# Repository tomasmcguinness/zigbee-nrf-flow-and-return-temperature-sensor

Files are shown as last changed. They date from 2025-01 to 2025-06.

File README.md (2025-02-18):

# Zigbee Flow and Return Temperature Sensor on nRF52840

A Zigbee Sensor designed to monitor flow and return temperatures. The sensor provides two temperature sensor probes in a single unit. It can be used to monitor a boiler's flow and return temperatures or the difference between the tails of a radiator.

It uses two NTC Thermistors, which can be attached to the flow and return pipes on whatever you wish to measure; radiator tails, boiler flow and return, hot water cylinder. 

Battery powered, this sensor should run for over about a year and a half on a coin battery or around ten years on a 2000mAh battery.

> [!IMPORTANT] 
> This is still a work in progress. I have included a short list of items at the end of this README

## Parts

* 1 x Seeed XIAO nRF52840
* 2 x 10kΩ 0.1% resistors
* 2 x NTC Thermistors (I use these TT0P-10KC3-T105-1500)
* 1 x push button

## Wiring

In the diagram below, you would replace the two 10kΩ thermistor that are not on the breadboard with the actual probes



## Compiling 

This code has been developed using NCS (nRF Connect Software), with pin outs and battery reading chosen for the Seeed XIAO nrf52840. It should run on any nRF52840 with some tweaking. There is an overlay included for the nRF52840DK, which I use for development.

To compile, run the following command in an `nRF Connect` terminal. The pristine build (-p) flag isn't always necessary.

```
west build -b xiao_ble -p
```

## Flashing

The XIAO board can be flashed using two methods. The first is done using the factory installed bootloader. The second is done using a J-Link programmer. I have a J-Link programmer, so that's the method I've been using.

### UF2

> [!CAUTION] 
> Whilst this method *should* work, I haven't have any success! I want to make this project accessible to those without a J-Link, so I will dedicate time to it.

First, connect the board via USB to your computer. Next, double click the Reset button. A new USB drive should appear.

The compilation process will generate a UF2 firmware file and it will be be located here:

```
zigbee-nrf-flow-and-return-temperature-sensor\build\zigbee-nrf-flow-and-return-temperature-sensor\zephyr\zephyr.uf2
```

Just copy and paste this file onto the USB drive and the application *should* start. 

### J-Link

If you have a J-Link programmer, connect the board and run this command.

```
west flash
```

## Pairing

Once you have flashed the nRF52840 and powered it up, it will enter pairing mode. You can then add it to your Zigbee network using your usual method.

# NTC Thermistors

My Zigbee sensor was build with the TT0P-10KC3-T105-1500 probes, as I have already mentioned. These have a nominal resistance of 10kΩ @ 25°C and have a beta value of 3977. The relevant definitions in the code are here.

```
#define THERMISTORNOMINAL 10000
#define TEMPERATURENOMINAL 25
#define BCOEFFICIENT 3977
#define SERIESRESISTOR 10000
```

> [!NOTE] 
> If you want to use a different thermistor, you can change these values. I plan on making these configurable via the project, but for now you will need to change them directly in code.

# GPIOs

There several GPIOs configured by this project. These have been picked for the Seeed XIAO nRF52840 board.



| GPIO  | Usage |
| --- | --- |
| P0.03 | ADC (AIN1) pin for Probe 1  |
| P0.29 | ADC (AIN5) pin for Probe 2  |
| P0.28 | Power for the voltage dividers connected to the NTC temperature probes |
| P1.13 | Reset pin. Apply high for 10 seconds to reset the Zigbee configuration | 

# Zigbee ZCL

In order to maintain compatability, this sensor uses standard ZCL clusters rather.

There are three Endpoints 1, 5 & 7

Endpoint 1 contains the Basic cluster, the Identify Cluster and the Power Configuration Cluster.
Endpoint 5 contains a Temperature Measurement Cluster
Endpoint 7 contains a Temperature Measurement Cluster

# Home Assistant

I have tested my sensor on HomeAssistant using the ZHA integration and it displays pretty well. 



Unfortunately, the probe names are terrible.

```
sensor.coldbear_fart_sensor_temperature
sensor.coldbear_fart_sensor_temperature_2
```

I have tried to make a ZHA "Quirk" to display the probes like this:

```
sensor.coldbear_fart_sensor_flow_temperature
sensor.coldbear_fart_sensor_return_temperature
```

but I haven't had any success yet making it work how I want. I have included my work in progress in the project.

# Battery Life

I've invested a lot of time to try and ensure long battery life and I think I've gotten it to over a year on a coin battery! Average consumption is around 16µA



I've written quite a few blog posts detailing the journey, which are up on my blog. You can start here:

https://tomasmcguinness.com/2024/12/19/reducing-power-consumption-in-my-nrf52840-zigbee-sensor-with-the-help-of-a-nordic-semiconductors-power-profiler-ii-kit/

# Setup

Once powered up, you can add the device to your Zigbee network as you would any other Zigbee device.

# PCB

Using KiCAD, I have designed a PCB for this code. 

## V2
A mix of SMD and throughhole mountings, this revision fixes the traces for the reset button (issue in V1) and uses updated footprints for the JST connectors.



> [!CAUTION]
> The battery connections on this PCB are just very difficult to make. I've tried on three different boards, but I've not managed to power the XIAO using the battery terminal. If you had a finer soldering iron, you might have better luck.

## V3
To work around the battery terminal issue and make it easier to for amateurs like myself to solder, V3 has switched to a socket mount for the XIAO board. I also hope to use pogo pins to make the battery connections.



> [!NOTE]
> As of the 15th Feb 2025, I am waiting on the first fabricated versions of this board to verify the socket and pogo pin design will work. 

## V4
This is incomplete. The goal is to move to SMD mounting compleletely and introduce a CR2032 battery holder to make the unit complete. It's present in the PCB-V4 branch.

> [!CAUTION]
> V4 is a work in progress and not ready for use!

All the external connections for NTC probes and battery are via JST connectors.

If you are interested in buying a PCB, do let me know. If there is enough interest, I can place a bulk order.

# Support

If you want to support this project, please consider buying me a coffee!



# Next Steps

* [x] ~~Fix reset button PCB traces~~
* [x] ~~Use reset button to reverse probes i.e. swap readings~~
* [ ] Indicate when probes are swapped
* [ ] Confirm long-term reliability
* [ ] Ensure battery life

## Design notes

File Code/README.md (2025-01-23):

# Zigbee F.A.R.T. Sensor (Flow and Return Temperature)

A Zigbee Sensor designed to monitor flow and return temperatures. The sensor provides two temperature sensor probes in a single unit. It can be used to monitor a boiler's flow and return temperatures or the different between the tails of a radiator.

Battery powered, this sensor should run for over a year on a coin battery or 10 years on a 2000mAh battery.

## Compiling 

This code has been developed using NCS (nRF Connect Software), with pin outs and battery reading chosen for the Seeed XIAO nrf52840. It should run on any nRF52840 with some tweaking. 

To compile, run the following command in an `nRF Connect` terminal. The pristine build (-p) flag isn't always necessary.

```
west build -b xiao_ble -p
```

## Flashing

The XIAO board can be flashed using two methods. The first is done using the factory installed bootloader. The second is done using a J-Link programmer. I have a J-Link programmer, so that's the method I've been using.

### UF2

[!IMPORTANT]
Whilst this is supported, I have tried it without success! I want to make this project accessible to those without a J-Link, so I will dedicate time to it.

First, connect the board via USB to your computer. Next, double click the Reset button. A new USB drive should appear.

The compilation process will generate a UF2 firmware file and it will be be located here:

```
zigbee-nrf-flow-and-return-temperature-sensor\build\zigbee-nrf-flow-and-return-temperature-sensor\zephyr\zephyr.uf2
```

Just copy and paste this file onto the USB drive and the application *should* start. 

### J-Link

If you have a J-Link programmer, connect the board and run this command.

```
west flash
```

## GPIOs

There several GPIOs configured. These have been picked for the Seeed XIAO nRF52840 board.



P0.03 is the ADC (AIN1) pin for Probe 1
P0.28 is the ADC (AIN5) pin for Probe 2 
P0.28 providers power for the voltage dividers connected to the NTC temperature probes

P1.13 is the reset pin. Apply high for 10 seconds to reset the Zigbee configuration.

## Zigbee ZCL

In order to maintain compatability, this sensor uses standard ZCL clusters.

There are three Endpoints 1, 5 & 7

Endpoint 1 contains the Basic cluster, the Identify Cluster and the Power Configuration Cluster.
Endpoint 5 contains a Temperature Measurement Cluster
Endpoint 7 contains a Temperature Measurement Cluster

## Battery Life

I've invested a lot of time to try and ensure long battery life. I've written a few blog posts detailing the journey, which are up on my blog. You can start here:

https://tomasmcguinness.com/2024/12/19/reducing-power-consumption-in-my-nrf52840-zigbee-sensor-with-the-help-of-a-nordic-semiconductors-power-profiler-ii-kit/

# Setup

Once powered up, you can add the device to your Zigbee network as you would any other.

# PCB

I have designed a PCB for this code, but there are some flaws in it, so I'm not ready to make it public just yet! If you are interested in buying a PCB, let me know. If there are enough orders, the price per board can be quite low.

# Next Steps

* [ ] Use reset button to reverse probes i.e. swap readings
* [ ] Ensure reliability
* [ ] Ensure battery life

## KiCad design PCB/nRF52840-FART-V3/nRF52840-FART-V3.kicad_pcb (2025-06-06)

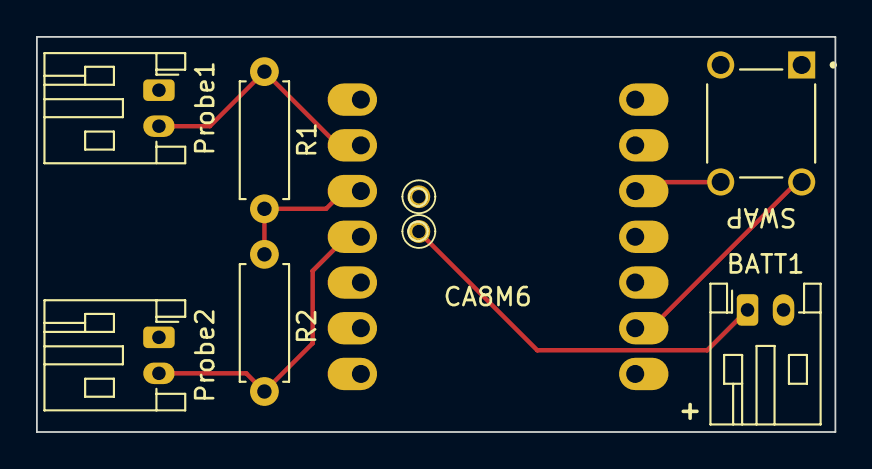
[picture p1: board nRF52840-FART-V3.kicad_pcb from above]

Board: 2 copper layers, 44.4 x 22.0 mm, 9 parts (0 on the bottom side), 7 nets.

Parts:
BATT1: Conn_01x02_Pin; JST_PH_S2B-PH-K_1x02_P2.00mm_Horizontal
J1, J2: 0914-3-15-20-77-14-11-0; 0914315207714110
Probe1, Probe2: Conn_01x02_Pin; JST_PH_S2B-PH-K_1x02_P2.00mm_Horizontal
R1, R2: 10K; R_Axial_DIN0207_L6.3mm_D2.5mm_P7.62mm_Horizontal
S1: TS02-66-55-BK-100-LCR-D; SW_TS02-66-55-BK-100-LCR-D
U1: xiao-ble; xiao-ble-tht

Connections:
+3.3V: S1.4, U1.12 (3V3)
+BATT: BATT1.1, J2.1
/dividerPower: R1.2, R2.2, U1.3 (A10/0.28)
/p1reading: Probe1.2, R1.1, U1.2 (A4/0.03_H)
/p2reading: Probe2.2, R2.1, U1.4 (A11/0.29)
/reset: S1.2, U1.9 (A7_SCK/1.13)
GND: BATT1.2, J1.1, Probe1.1, Probe2.1

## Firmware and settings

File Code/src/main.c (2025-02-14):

/*
 * Copyright (c) Cold Bear Ltd
 *
 * SPDX-License-Identifier: MIT
 */

#include <zephyr/kernel.h>
#include <zephyr/logging/log.h>
#include <zephyr/device.h>
#include <zephyr/devicetree.h>
#include <zephyr/drivers/adc.h>
#include <zephyr/drivers/gpio.h>
#include <zephyr/settings/settings.h>
#include <zephyr/pm/policy.h>
#include <zboss_api.h>
#include <zboss_api_addons.h>
#include <zigbee/zigbee_app_utils.h>
#include <zigbee/zigbee_error_handler.h>
#include <zb_nrf_platform.h>
#include <zb_zcl_reporting.h>
#include <zb_nrf_platform.h>
#include <zephyr/drivers/flash.h>
#include <zephyr/storage/flash_map.h>
#include <zephyr/fs/nvs.h>

#include "ha/zb_ha_temperature_sensor.h"

#include <math.h>

#include <dk_buttons_and_leds.h>
#include <ram_pwrdn.h>

#include "flash.h"

static struct nvs_fs fs;

/* This storage_partition is defined by the standard Zephyr Overlay */
#define NVS_PARTITION storage_partition
#define NVS_PARTITION_DEVICE FIXED_PARTITION_DEVICE(NVS_PARTITION)
#define NVS_PARTITION_OFFSET FIXED_PARTITION_OFFSET(NVS_PARTITION)

#define RED_LED_NODE DT_ALIAS(led0)
#define GREEN_LED_NODE DT_ALIAS(led1)
#define BLUE_LED_NODE DT_ALIAS(led2)

#define TEMPERATURE_DIVIDER_POWER_NODE DT_NODELABEL(temperature_divider_power)
#define ACTION_BUTTON_NODE DT_ALIAS(sw0)
#define BATTERY_DIVIDER_SINK_NODE DT_NODELABEL(battery_divider_sink)

#define APP_LOOP_INTERVAL_SEC 30
#define IDENTIFY_LED_BLINK_MSEC 100

#define SWAP_PROBES_PROBE_TIME K_SECONDS(1)

#define ZCL_TEMPERATURE_MEASUREMENT_MEASURED_VALUE_MULTIPLIER 100

#define INIT_BASIC_POWER_SOURCE ZB_ZCL_BASIC_POWER_SOURCE_BATTERY

#define INIT_BASIC_MANUF_NAME "coldbear"
#define INIT_BASIC_MODEL_ID "FART Sensor"
#define INIT_BASIC_HW_VERSION 11
#define INIT_BASIC_SW_VERSION "v0.1"
#define INIT_BASIC_APP_VERSION 01
#define INIT_BASIC_STACK_VERSION 10

#define FART_ENDPOINT 1
#define PROBE_1_ENDPOINT 5
#define PROBE_2_ENDPOINT 7

#define BATTERY_ADC_CHANNEL 2

#define DT_SPEC_AND_COMMA(node_id, prop, idx) ADC_DT_SPEC_GET_BY_IDX(node_id, idx),

static const struct adc_dt_spec adc_channels[] = {DT_FOREACH_PROP_ELEM(DT_PATH(zephyr_user), io_channels, DT_SPEC_AND_COMMA)};

static const struct adc_dt_spec adc_channels[];

struct swap_probes_context_t
{
	uint32_t button;
	bool swap_done;
	struct k_timer timer;
};
static struct swap_probes_context_t swap_probes_context;

static bool probes_swapped = false;

// TODO Move this to configuration, so they can be easily changed.
//
#define THERMISTORNOMINAL 10000
#define TEMPERATURENOMINAL 25
#define BCOEFFICIENT 3977
#define SERIESRESISTOR 10000

static const struct gpio_dt_spec red_led = GPIO_DT_SPEC_GET(RED_LED_NODE, gpios);
static const struct gpio_dt_spec green_led = GPIO_DT_SPEC_GET(GREEN_LED_NODE, gpios);
static const struct gpio_dt_spec blue_led = GPIO_DT_SPEC_GET(BLUE_LED_NODE, gpios);
static const struct gpio_dt_spec temperatures_divider_power = GPIO_DT_SPEC_GET(TEMPERATURE_DIVIDER_POWER_NODE, gpios);
static const struct gpio_dt_spec battery_divider_sink = GPIO_DT_SPEC_GET(BATTERY_DIVIDER_SINK_NODE, gpios);

LOG_MODULE_REGISTER(app, LOG_LEVEL_DBG);

typedef struct
{
	zb_uint8_t battery_voltage;
	zb_uint8_t battery_size;
	zb_uint8_t battery_quantity;
	zb_uint8_t battery_rated_voltage;
	zb_uint8_t battery_alarm_mask;
	zb_uint8_t battery_voltage_min_threshold;
	zb_uint8_t battery_percentage_remaining;
	zb_uint8_t battery_voltage_threshold1;
	zb_uint8_t battery_voltage_threshold2;
	zb_uint8_t battery_voltage_threshold3;
	zb_uint8_t battery_percentage_min_threshold;
	zb_uint8_t battery_percentage_threshold1;
	zb_uint8_t battery_percentage_threshold2;
	zb_uint8_t battery_percentage_threshold3;
	zb_uint32_t battery_alarm_state;

} zb_zcl_power_config_battery_attrs_t;

struct zb_device_ctx
{
	zb_zcl_basic_attrs_ext_t basic_attr;
	zb_zcl_identify_attrs_t identify_attr;
	zb_zcl_temp_measurement_attrs_t probe_1_measure_attrs;
	zb_zcl_temp_measurement_attrs_t probe_2_measure_attrs;
	zb_zcl_power_config_battery_attrs_t power_config_attrs;
};

static struct zb_device_ctx dev_ctx;

struct battery_level_point
{
	// Percentage at #lvl_mV.
	uint8_t lvl_percentage;

	// Voltage at #lvl_percentage remaining life. */
	uint16_t lvl_mV;
};

/** A discharge curve specific to the power source. */
static const struct battery_level_point levels[] = {
	/* "Curve" here eyeballed from captured data for the [Adafruit
	 * 3.7v 2000 mAh](https://www.adafruit.com/product/2011) LIPO
	 * under full load that started with a charge of 3.96 V and
	 * dropped about linearly to 3.58 V over 15 hours.  It then
	 * dropped rapidly to 3.10 V over one hour, at which point it
	 * stopped transmitting.
	 *
	 * Based on eyeball comparisons we'll say that 15/16 of life
	 * goes between 3.95 and 3.55 V, and 1/16 goes between 3.55 V
	 * and 3.1 V.
	 */

	{100, 3700},
	{6, 3550},
	{0, 3100},
};

//------------
// Prototypes
//

void zboss_signal_handler(zb_bufid_t bufid);
static void zcl_device_cb(zb_bufid_t bufid);
static void configure_gpio(void);
static void app_clusters_attr_init(void);
static void identify_cb(zb_bufid_t bufid);
static void button_handler(uint32_t button_state, uint32_t has_changed);
static void toggle_identify_led(zb_bufid_t bufid);
static int read_battery();
static int read_temperatures();
void check_swap_probes_button(uint32_t button_state, uint32_t has_changed);
static void swap_probes_timer_expired(struct k_timer *timer_id);
static void register_swap_probes_button(uint8_t button);

ZB_ZCL_DECLARE_IDENTIFY_ATTRIB_LIST(
	identify_attr_list,
	&dev_ctx.identify_attr.identify_time);

ZB_ZCL_DECLARE_BASIC_ATTRIB_LIST_EXT(
	ext_attr_list,
	&dev_ctx.basic_attr.zcl_version,
	&dev_ctx.basic_attr.app_version,
	&dev_ctx.basic_attr.stack_version,
	&dev_ctx.basic_attr.hw_version,
	&dev_ctx.basic_attr.mf_name,
	&dev_ctx.basic_attr.model_id,
	&dev_ctx.basic_attr.zcl_version,
	&dev_ctx.basic_attr.power_source,
	&dev_ctx.basic_attr.location_id,
	&dev_ctx.basic_attr.ph_env,
	&dev_ctx.basic_attr.sw_ver);

// This must be declared for compilate to succeed.
// https://devzone.nordicsemi.com/f/nordic-q-a/85315/zboss-declare-power-config-attribute-list-for-battery-bat_num
#define bat_num

ZB_ZCL_DECLARE_POWER_CONFIG_BATTERY_ATTRIB_LIST_EXT(power_config_attr_list,
													&dev_ctx.power_config_attrs.battery_voltage,
													&dev_ctx.power_config_attrs.battery_size,
													&dev_ctx.power_config_attrs.battery_quantity,
													&dev_ctx.power_config_attrs.battery_rated_voltage,
													&dev_ctx.power_config_attrs.battery_alarm_mask,
													&dev_ctx.power_config_attrs.battery_voltage_min_threshold,
													&dev_ctx.power_config_attrs.battery_percentage_remaining,
													&dev_ctx.power_config_attrs.battery_voltage_threshold1,
													&dev_ctx.power_config_attrs.battery_voltage_threshold2,
													&dev_ctx.power_config_attrs.battery_voltage_threshold3,
													&dev_ctx.power_config_attrs.battery_percentage_min_threshold,
													&dev_ctx.power_config_attrs.battery_percentage_threshold1,
													&dev_ctx.power_config_attrs.battery_percentage_threshold2,
													&dev_ctx.power_config_attrs.battery_percentage_threshold3,
													&dev_ctx.power_config_attrs.battery_alarm_state);

ZB_ZCL_DECLARE_FART_SENSOR_CLUSTER_LIST(fart_sensor_clusters, ext_attr_list, identify_attr_list, power_config_attr_list);
ZB_HA_DECLARE_FART_SENSOR_EP(fart_sensor_ep, FART_ENDPOINT, fart_sensor_clusters);

ZB_ZCL_DECLARE_TEMP_MEASUREMENT_ATTRIB_LIST(temp_measurement_attr_list_1,
											&dev_ctx.probe_1_measure_attrs.measure_value,
											&dev_ctx.probe_1_measure_attrs.min_measure_value,
											&dev_ctx.probe_1_measure_attrs.max_measure_value,
											&dev_ctx.probe_1_measure_attrs.tolerance);

ZB_HA_DECLARE_TEMPERATURE_SENSOR_CLUSTER_LIST(temperature_sensor_clusters_1, temp_measurement_attr_list_1);
ZB_HA_DECLARE_TEMPERATURE_SENSOR_EP_1(temperature_sensor_ep_one, PROBE_1_ENDPOINT, temperature_sensor_clusters_1);

ZB_ZCL_DECLARE_TEMP_MEASUREMENT_ATTRIB_LIST(temp_measurement_attr_list_2,
											&dev_ctx.probe_2_measure_attrs.measure_value,
											&dev_ctx.probe_2_measure_attrs.min_measure_value,
											&dev_ctx.probe_2_measure_attrs.max_measure_value,
											&dev_ctx.probe_2_measure_attrs.tolerance);

ZB_HA_DECLARE_TEMPERATURE_SENSOR_CLUSTER_LIST(temperature_sensor_clusters_2, temp_measurement_attr_list_2);
ZB_HA_DECLARE_TEMPERATURE_SENSOR_EP_2(temperature_sensor_ep_two, PROBE_2_ENDPOINT, temperature_sensor_clusters_2);

ZBOSS_DECLARE_DEVICE_CTX_3_EP(device_ctx, fart_sensor_ep, temperature_sensor_ep_one, temperature_sensor_ep_two);

// Taken from https://forum.seeedstudio.com/t/low-power-with-xiao-nrf52840-on-zephyr-rtos/270491/5
/* Prevent deep sleep (system off) from being entered on long timeouts
 * or `K_FOREVER` due to the default residency policy.
 *
 * This has to be done before anything tries to sleep, which means
 * before the threading system starts up between PRE_KERNEL_2 and
 * POST_KERNEL.  Do it at the start of PRE_KERNEL_2.
 */
static int disable_ds_1(const struct device *dev)
{
	ARG_UNUSED(dev);

	pm_policy_state_lock_get(PM_STATE_SOFT_OFF, PM_ALL_SUBSTATES);
	return 0;
}

SYS_INIT(disable_ds_1, PRE_KERNEL_2, 0);

static void app_loop(zb_bufid_t bufid)
{
	ZVUNUSED(bufid);

	LOG_INF("APP_LOOP");

	int rc;

	if (ZB_JOINED())
	{
		LOG_INF("Updating sensor values...");

		rc = read_temperatures();
		rc = read_battery();

		rc = ZB_SCHEDULE_APP_ALARM(app_loop, ZB_ALARM_ANY_PARAM, ZB_MILLISECONDS_TO_BEACON_INTERVAL(APP_LOOP_INTERVAL_SEC * 1000));

		if (rc != RET_OK)
		{
			LOG_ERR("Failed to schedule app_loop");
		}
	}
	else
	{
		LOG_INF("Waiting to join network");

		// Toggle the LED. This will cause it to blink on & every every one second.
		//
		rc = gpio_pin_toggle_dt(&blue_led);

		if (rc != RET_OK)
		{
			LOG_ERR("Failed to toggle identify LED");
		}

		rc = ZB_SCHEDULE_APP_ALARM(app_loop, ZB_ALARM_ANY_PARAM, ZB_MILLISECONDS_TO_BEACON_INTERVAL(1000));

		if (rc != RET_OK)
		{
			LOG_ERR("Failed to schedule app_loop");
		}
	}
}

#define SWAP_PROBES_ID 1

int main(void)
{
	LOG_INF("Starting Zigbee F.A.R.T. Sensor");

	int rc;

	struct flash_pages_info info;

	/* define the nvs file system by settings with:
	 *	sector_size equal to the pagesize,
	 *	3 sectors
	 *	starting at NVS_PARTITION_OFFSET
	 */
	fs.flash_device = NVS_PARTITION_DEVICE;
	if (!device_is_ready(fs.flash_device))
	{
		LOG_ERR("Flash device %s is not ready", fs.flash_device->name);
		return 0;
	}
	fs.offset = NVS_PARTITION_OFFSET;
	rc = flash_get_page_info_by_offs(fs.flash_device, fs.offset, &info);
	if (rc)
	{
		LOG_ERR("Unable to get page info, rc=%d", rc);
		return 0;
	}
	fs.sector_size = info.size;
	fs.sector_count = 3U;

	rc = nvs_mount(&fs);
	if (rc)
	{
		LOG_ERR("Flash Init failed, rc=%d", rc);
		return 0;
	}

	uint8_t buf[1];

	rc = nvs_read(&fs, SWAP_PROBES_ID, &buf, sizeof(buf));

	if (rc > 0)
	{
		LOG_INF("Swap Probes: %d", buf);
		probes_swapped = buf[0];
	}
	else
	{
		buf[0] = 0x00;

		LOG_INF("No Swap Probes configuration found. Setting initial value...");
		(void)nvs_write(&fs, SWAP_PROBES_ID, &buf, sizeof(buf));
	}

	// Taken from https://forum.seeedstudio.com/t/low-power-with-xiao-nrf52840-on-zephyr-rtos/270491/5
	// This turns off the QSPI flash and reduces power consumption.
	//
	da_flash_init();
	da_flash_command(0xB9);
	da_flash_uninit();

	configure_gpio();

	// WTF does "4" represent? It's the button's "state" value. The mask?
	//
	register_swap_probes_button(4);
	register_factory_reset_button(4);

	zb_set_ed_timeout(ED_AGING_TIMEOUT_64MIN);

	zb_set_keepalive_timeout(ZB_MILLISECONDS_TO_BEACON_INTERVAL(60000));

	zb_set_rx_on_when_idle(ZB_FALSE);

	ZB_ZCL_REGISTER_DEVICE_CB(zcl_device_cb);

	ZB_AF_REGISTER_DEVICE_CTX(&device_ctx);

	app_clusters_attr_init();

	ZB_AF_SET_IDENTIFY_NOTIFICATION_HANDLER(FART_ENDPOINT, identify_cb);

	zb_bdb_set_legacy_device_support(1);

	zigbee_configure_sleepy_behavior(true);

	power_down_unused_ram();

	for (size_t i = 0U; i < ARRAY_SIZE(adc_channels); i++)
	{
		if (!device_is_ready(adc_channels[i].dev))
		{
			LOG_ERR("ADC controller device not ready");
			return -1;
		}

		rc = adc_channel_setup_dt(&adc_channels[i]);

		if (rc < 0)
		{
			LOG_ERR("Could not setup channel #%d (%d)", i, rc);
			return -1;
		}

		LOG_INF("Setup channel #%d (%d)", i, rc);
	}

	// nrf_802154_tx_power_set(8);

	zigbee_enable();

	// Start the app loop.
	//
	ZB_SCHEDULE_APP_CALLBACK(app_loop, ZB_ALARM_ANY_PARAM);

	// Zigbee will take it from here. Put this thread to sleep forever
	//
	while (1)
	{
		LOG_INF("Everything is setup. Main thread will now go to sleep");
		k_sleep(K_FOREVER);
	}
}

static void register_swap_probes_button(uint8_t button)
{
	swap_probes_context.button = button;
	swap_probes_context.swap_done = false;

	k_timer_init(&swap_probes_context.timer, swap_probes_timer_expired, NULL);
}

static void swap_probes(zb_bufid_t bufid)
{
	ZVUNUSED(bufid);

	probes_swapped = !probes_swapped;

	LOG_INF("Updating swap probes to [%d]", probes_swapped);

	uint8_t buf[1];

	buf[0] = probes_swapped;

	(void)nvs_write(&fs, SWAP_PROBES_ID, &buf, sizeof(buf));

	// TODO Turn the light green or indicate the active probe??
	// Red mean probe 1 is flow, green means probe 2 is flow?
}

static void swap_probes_timer_expired(struct k_timer *timer_id)
{
	uint32_t button_state = 0;
	uint32_t has_changed = 0;

	dk_read_buttons(&button_state, &has_changed);

	if (button_state & swap_probes_context.button)
	{
		LOG_DBG("FR button pressed for %d [s]", timer_id->status);

		if (timer_id->status >= CONFIG_SWAP_PROBES_PRESS_TIME_SECONDS)
		{
			LOG_DBG("Schedule Swap Probes; stop timer; set swap_done flag");
			ZB_SCHEDULE_APP_CALLBACK(swap_probes, 0);
			k_timer_stop(timer_id);
			swap_probes_context.swap_done = true;
		}
	}
	else
	{
		LOG_DBG("FR button released prematurely, swap cancelled");
		k_timer_stop(timer_id);
	}
}

void check_swap_probes_button(uint32_t button_state, uint32_t has_changed)
{
	if (button_state & has_changed & swap_probes_context.button)
	{
		LOG_INF("Clear check_swap_probes_button flag; start Swap Probes timer");

		/* Reset flag indicating that Swap Probes was initiated */
		swap_probes_context.swap_done = false;

		/* Start timer checking button press time */
		k_timer_start(&swap_probes_context.timer, SWAP_PROBES_PROBE_TIME, SWAP_PROBES_PROBE_TIME);
	}
}

static void button_handler(uint32_t button_state, uint32_t has_changed)
{
	LOG_INF("button_handler: %d", button_state);

	check_swap_probes_button(button_state, has_changed);

	check_factory_reset_button(button_state, has_changed);

	user_input_indicate();
}

static void app_clusters_attr_init(void)
{
	dev_ctx.basic_attr.zcl_version = ZB_ZCL_VERSION;
	dev_ctx.basic_attr.power_source = INIT_BASIC_POWER_SOURCE;
	dev_ctx.basic_attr.stack_version = INIT_BASIC_STACK_VERSION;
	dev_ctx.basic_attr.hw_version = INIT_BASIC_HW_VERSION;
	dev_ctx.basic_attr.power_source = ZB_ZCL_BASIC_POWER_SOURCE_BATTERY;
	dev_ctx.basic_attr.ph_env = ZB_ZCL_BASIC_ENV_UNSPECIFIED;

	dev_ctx.identify_attr.identify_time = ZB_ZCL_IDENTIFY_IDENTIFY_TIME_DEFAULT_VALUE;

	ZB_ZCL_SET_STRING_VAL(
		dev_ctx.basic_attr.mf_name,
		INIT_BASIC_MANUF_NAME,
		ZB_ZCL_STRING_CONST_SIZE(INIT_BASIC_MANUF_NAME));

	ZB_ZCL_SET_STRING_VAL(
		dev_ctx.basic_attr.model_id,
		INIT_BASIC_MODEL_ID,
		ZB_ZCL_STRING_CONST_SIZE(INIT_BASIC_MODEL_ID));

	// Set the measurements to zero.
	//
	dev_ctx.probe_1_measure_attrs.measure_value = 0;
	dev_ctx.probe_2_measure_attrs.measure_value = 0;

	ZB_ZCL_SET_ATTRIBUTE(PROBE_1_ENDPOINT,
						 ZB_ZCL_CLUSTER_ID_TEMP_MEASUREMENT,
						 ZB_ZCL_CLUSTER_SERVER_ROLE,
						 ZB_ZCL_ATTR_TEMP_MEASUREMENT_VALUE_ID,
						 (zb_uint8_t *)&dev_ctx.probe_1_measure_attrs.measure_value,
						 ZB_FALSE);

	ZB_ZCL_SET_ATTRIBUTE(PROBE_2_ENDPOINT,
						 ZB_ZCL_CLUSTER_ID_TEMP_MEASUREMENT,
						 ZB_ZCL_CLUSTER_SERVER_ROLE,
						 ZB_ZCL_ATTR_TEMP_MEASUREMENT_VALUE_ID,
						 (zb_uint8_t *)&dev_ctx.probe_2_measure_attrs.measure_value,
						 ZB_FALSE);

	// Set battery measurements
	//
	dev_ctx.power_config_attrs.battery_voltage = ZB_ZCL_POWER_CONFIG_BATTERY_VOLTAGE_INVALID;
	dev_ctx.power_config_attrs.battery_percentage_remaining = ZB_ZCL_POWER_CONFIG_BATTERY_REMAINING_UNKNOWN;
	dev_ctx.power_config_attrs.battery_quantity = 1;
	dev_ctx.power_config_attrs.battery_size = ZB_ZCL_POWER_CONFIG_BATTERY_SIZE_DEFAULT_VALUE;
}

static void configure_gpio(void)
{
	int err;

	err = dk_buttons_init(button_handler);
	if (err)
	{
		LOG_ERR("Cannot init buttons (err: %d)", err);
		return;
	}

	if (!gpio_is_ready_dt(&blue_led))
	{
		LOG_ERR("Blue LED not ready");
		return;
	}

	err = gpio_pin_configure_dt(&blue_led, GPIO_OUTPUT_HIGH);
	if (err != 0)
	{
		LOG_ERR("Cannot configure Blue LED (err: %d)", err);
		return;
	}

	if (!gpio_is_ready_dt(&temperatures_divider_power))
	{
		LOG_ERR("Cannot configure Divider Power switch (err: %d)", err);
		return;
	}

	err = gpio_pin_configure_dt(&temperatures_divider_power, GPIO_OUTPUT_INACTIVE);
	if (err != 0)
	{
		LOG_ERR("Configuring Divider Power pin failed (err: %d)", err);
		return;
	}

	// Switch the battery sink on. Leave it on for the duration.
	// This is the recommended practice with a battery attached to prevent burning out the ADC.
	//
	err = gpio_pin_configure_dt(&battery_divider_sink, GPIO_OUTPUT_ACTIVE);
	if (err != 0)
	{
		LOG_ERR("Configuring Battery Divider Sink pin failed (err: %d)", err);
		return;
	}
}

static void toggle_identify_led(zb_bufid_t bufid)
{
	LOG_DBG("toggle_identify_led()");

	gpio_pin_toggle_dt(&blue_led);

	zb_ret_t zb_err_code = ZB_SCHEDULE_APP_ALARM(toggle_identify_led, bufid, ZB_MILLISECONDS_TO_BEACON_INTERVAL(IDENTIFY_LED_BLINK_MSEC));

	if (zb_err_code != RET_OK)
	{
		LOG_ERR("Could not schedule identify alarm");
	}
}

static void start_identifying(zb_bufid_t bufid)
{
	LOG_INF("start_identifying() has been called!");

	ZVUNUSED(bufid);

	if (ZB_JOINED())
	{
		/* Check if endpoint is in identifying mode,
		 * if not put desired endpoint in identifying mode.
		 */
		if (dev_ctx.identify_attr.identify_time == ZB_ZCL_IDENTIFY_IDENTIFY_TIME_DEFAULT_VALUE)
		{
			zb_ret_t zb_err_code = zb_bdb_finding_binding_target(PROBE_1_ENDPOINT);

			if (zb_err_code == RET_OK)
			{
				LOG_INF("Enter identify mode");
			}
			else if (zb_err_code == RET_INVALID_STATE)
			{
				LOG_WRN("RET_INVALID_STATE - Cannot enter identify mode");
			}
			else
			{
				ZB_ERROR_CHECK(zb_err_code);
			}
		}
		else
		{
			LOG_INF("Cancel identify mode");
			zb_bdb_finding_binding_target_cancel();
		}
	}
	else
	{
		LOG_WRN("Device not in a network - cannot enter identify mode");
	}
}

/* Invoked by ZBOSS. This will be called again with no buffer to turn off the identify mode */
static void identify_cb(zb_bufid_t bufid)
{
	zb_ret_t zb_err_code;

	if (bufid)
	{
		LOG_INF("identication started!");

		zb_err_code = ZB_SCHEDULE_APP_CALLBACK(toggle_identify_led, bufid);

		if (zb_err_code != RET_OK)
		{
			LOG_ERR("Could not set identify callback");
		}
	}
	else
	{
		LOG_INF("identication finished!");

		// There might be a pending alarm, so be cancel it.
		//
		zb_err_code = ZB_SCHEDULE_APP_ALARM_CANCEL(toggle_identify_led, ZB_ALARM_ANY_PARAM);
		ZVUNUSED(zb_err_code);

		// Ensure the LED is turned off when identification is finished.
		//
		gpio_pin_set_dt(&blue_led, 0);
	}
}

void zboss_signal_handler(zb_uint8_t param)
{
	zb_zdo_app_signal_hdr_t *sig_hndler = NULL;
	zb_zdo_app_signal_type_t sig = zb_get_app_signal(param, &sig_hndler);
	zb_ret_t status = ZB_GET_APP_SIGNAL_STATUS(param);

	LOG_INF("ZB signal (%u, status: %d)", sig, status);

	zigbee_default_signal_handler(param);

	switch (sig)
	{
	case ZB_BDB_SIGNAL_DEVICE_FIRST_START:
	case ZB_BDB_SIGNAL_DEVICE_REBOOT:
	{
		LOG_INF("Device starting or rebooting");

		// Ensure the LED is turned off
		//
		gpio_pin_set_dt(&blue_led, 0);

		// Call the app loop
		//
		ZB_SCHEDULE_APP_ALARM(app_loop, ZB_ALARM_ANY_PARAM, ZB_MILLISECONDS_TO_BEACON_INTERVAL(APP_LOOP_INTERVAL_SEC * 1000));
	}
	break;
	case ZB_DEVICE_LEFT:
	{
		LOG_INF("Device has left the network");
	}
	break;
	case ZB_COMMON_SIGNAL_CAN_SLEEP:
	{
		zb_zdo_signal_can_sleep_params_t *can_sleep_params = ZB_ZDO_SIGNAL_GET_PARAMS(sig_hndler, zb_zdo_signal_can_sleep_params_t);
		LOG_INF("Device can sleep for %d ms", can_sleep_params->sleep_tmo);
		zb_sleep_now();
	}
	break;
	}

	zb_buf_free(param);
}

static void zcl_device_cb(zb_bufid_t bufid)
{
	zb_zcl_device_callback_param_t *device_cb_param = ZB_BUF_GET_PARAM(bufid, zb_zcl_device_callback_param_t);

	LOG_INF("%s id %hd", __func__, device_cb_param->device_cb_id);

	device_cb_param->status = RET_OK;
}

int16_t temperature_buf;

struct adc_sequence temperature_sequence = {
	.buffer = &temperature_buf,
	.buffer_size = sizeof(temperature_buf),
	.calibrate = true,
};

int16_t battery_buf;

struct adc_sequence battery_sequence = {
	.buffer = &battery_buf,
	.buffer_size = sizeof(battery_buf),
	.calibrate = true,
};

// The ADC has 4096 levels. The reference volage depends on the gain
//
float mv_per_lsb = 3000.0F / 4096.0F;	   // 0.6 / (1/5) = 3
float batt_mv_per_lsb = 3600.0F / 4096.0F; // 0.6 / (1/6) = 3.6
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

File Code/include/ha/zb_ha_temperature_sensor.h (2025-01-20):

/*
 * Copyright (c) Cold Bear Ltd
 *
 * SPDX-License-Identifier: MIT
 */

#ifndef ZB_HA_TEMPERATURE_SENSOR_H
#define ZB_HA_TEMPERATURE_SENSOR_H 1

#define ZB_HA_DEVICE_VER_FART_SENSOR 0
#define ZB_HA_DEVICE_VER_TEMPERATURE_SENSOR 0

// Two measured_values and battery_remaining_percentage
#define ZB_REPORTING_ATTR_COUNT 20

#define ZB_FART_SENSOR_IN_CLUSTER_NUM 3
#define ZB_FART_SENSOR_OUT_CLUSTER_NUM 0

#define ZB_HA_TEMPERATURE_SENSOR_IN_CLUSTER_NUM 1
#define ZB_HA_TEMPERATURE_SENSOR_OUT_CLUSTER_NUM 0

#define ZB_ZCL_DECLARE_FART_SENSOR_CLUSTER_LIST(                          \
    cluster_list_name,                                                    \
    basic_attr_list,                                                      \
    identify_attr_list,                                                   \
    power_config_attr_list)                                               \
    zb_zcl_cluster_desc_t cluster_list_name[] =                           \
        {                                                                 \
            ZB_ZCL_CLUSTER_DESC(                                          \
                ZB_ZCL_CLUSTER_ID_POWER_CONFIG,                           \
                ZB_ZCL_ARRAY_SIZE(power_config_attr_list, zb_zcl_attr_t), \
                (power_config_attr_list),                                 \
                ZB_ZCL_CLUSTER_SERVER_ROLE,                               \
                ZB_ZCL_MANUF_CODE_INVALID),                               \
            ZB_ZCL_CLUSTER_DESC(                                          \
                ZB_ZCL_CLUSTER_ID_IDENTIFY,                               \
                ZB_ZCL_ARRAY_SIZE(identify_attr_list, zb_zcl_attr_t),     \
                (identify_attr_list),                                     \
                ZB_ZCL_CLUSTER_SERVER_ROLE,                               \
                ZB_ZCL_MANUF_CODE_INVALID),                               \
            ZB_ZCL_CLUSTER_DESC(                                          \
                ZB_ZCL_CLUSTER_ID_BASIC,                                  \
                ZB_ZCL_ARRAY_SIZE(basic_attr_list, zb_zcl_attr_t),        \
                (basic_attr_list),                                        \
                ZB_ZCL_CLUSTER_SERVER_ROLE,                               \
                ZB_ZCL_MANUF_CODE_INVALID)}

#define ZB_ZCL_DECLARE_FART_SENSOR_SIMPLE_DESC(ep_name, ep_id, in_clust_num, out_clust_num) \
    ZB_DECLARE_SIMPLE_DESC(in_clust_num, out_clust_num);                                    \
    ZB_AF_SIMPLE_DESC_TYPE(in_clust_num, out_clust_num)                                     \
    simple_desc_##ep_name =                                                                 \
        {                                                                                   \
            ep_id,                                                                          \
            ZB_AF_HA_PROFILE_ID,                                                            \
            ZB_HA_TEMPERATURE_SENSOR_DEVICE_ID,                                             \
            ZB_HA_DEVICE_VER_FART_SENSOR,                                                   \
            0,                                                                              \
            in_clust_num,                                                                   \
            out_clust_num,                                                                  \
            {ZB_ZCL_CLUSTER_ID_BASIC,                                                       \
             ZB_ZCL_CLUSTER_ID_IDENTIFY,                                                    \
             ZB_ZCL_CLUSTER_ID_POWER_CONFIG}}

#define ZB_HA_DECLARE_FART_SENSOR_EP(ep_name, ep_id, cluster_list)                      \
    ZB_ZCL_DECLARE_FART_SENSOR_SIMPLE_DESC(ep_name,                                     \
                                           ep_id,                                       \
                                           ZB_FART_SENSOR_IN_CLUSTER_NUM,               \
                                           ZB_FART_SENSOR_OUT_CLUSTER_NUM);             \
                                                                                        \
    ZBOSS_DEVICE_DECLARE_REPORTING_CTX(reporting_info_device_all_ep,                    \
                                       ZB_REPORTING_ATTR_COUNT);                        \
                                                                                        \
    ZB_AF_DECLARE_ENDPOINT_DESC(ep_name,                                                \
                                ep_id,                                                  \
                                ZB_AF_HA_PROFILE_ID,                                    \
                                0,                                                      \
                                NULL,                                                   \
                                ZB_ZCL_ARRAY_SIZE(cluster_list, zb_zcl_cluster_desc_t), \
                                cluster_list,                                           \
                                (zb_af_simple_desc_1_1_t *)&simple_desc_##ep_name,      \
                                ZB_REPORTING_ATTR_COUNT,                                \
                                reporting_info_device_all_ep,                           \
                                0,                                                      \
                                NULL);

#define ZB_HA_DECLARE_TEMPERATURE_SENSOR_CLUSTER_LIST(cluster_list_name, temp_measure_attr_list) \
    zb_zcl_cluster_desc_t cluster_list_name[] =                                                  \
        {                                                                                        \
            ZB_ZCL_CLUSTER_DESC(                                                                 \
                ZB_ZCL_CLUSTER_ID_TEMP_MEASUREMENT,                                              \
                ZB_ZCL_ARRAY_SIZE(temp_measure_attr_list, zb_zcl_attr_t),                        \
                (temp_measure_attr_list),                                                        \
                ZB_ZCL_CLUSTER_SERVER_ROLE,                                                      \
                ZB_ZCL_MANUF_CODE_INVALID)}
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

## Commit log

2025-01-21 Clean up some of the battery code and rename a few things. Remove the battery.c and .h files.
2025-01-21 Fix up the variable sizes so they are consistent. Add 2nd buffer for ADC reads to separate battery from temperature.
    [main.c]
2025-01-21 Remove vbatt and add comment about origin of battery percentage method
2025-01-23 Move to an app_loop instead of two threads. This is to improve stability.
    [main.c]
2025-01-25 Move code to its own folder
    [nRF52840-FART.kicad_pcb, nRF52840-FART.kicad_sch]
2025-01-25 Add a Fritz file
    [FART Sensor.fzz]
2025-01-27 Add some cancel alarm calls and check status codes to try and improve long term stability
    [main.c]
2025-01-27 Some new KiCAD backups.
2025-01-28 v0.2 of the PCB
    [nRF52840-FART.kicad_pcb, nRF52840-FART.kicad_sch]
2025-02-06 Update README.md
    Mark PCB traces as fixed
2025-02-09 KiCad backups
2025-02-09 Add timer callback for swap button behaviour. Start changes for NVS storage of swap setting.
    [main.c]
2025-02-12 Initial code to swap probes, but doesn't compile!
    [main.c]
2025-02-12 New PCB designs
    [nRF52840-FART-V3.kicad_pcb, nRF52840-FART-V3.kicad_sch, nRF52840-FART-V4.kicad_pcb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]
2025-02-14 Add red and gren LED configuration
2025-02-17 Remove V4 from main as it's not ready.
    [nRF52840-FART-V4.kicad_pcb, nRF52840-FART-V4.kicad_sch]
2025-06-06 Tweaks to the PCB design
    [nRF52840-FART-V3.kicad_pcb, nRF52840-FART-V3.kicad_sch]
2025-07-24 Fix reset button configuration.
2025-07-24 More messing with the PCB
2025-07-25 Switch power off gpio0/14 as that's LED2 on the DK
